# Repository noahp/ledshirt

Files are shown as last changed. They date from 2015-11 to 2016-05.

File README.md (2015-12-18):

# Ledshirt Readme
Battery powered LED flasher.

# Block Diagram
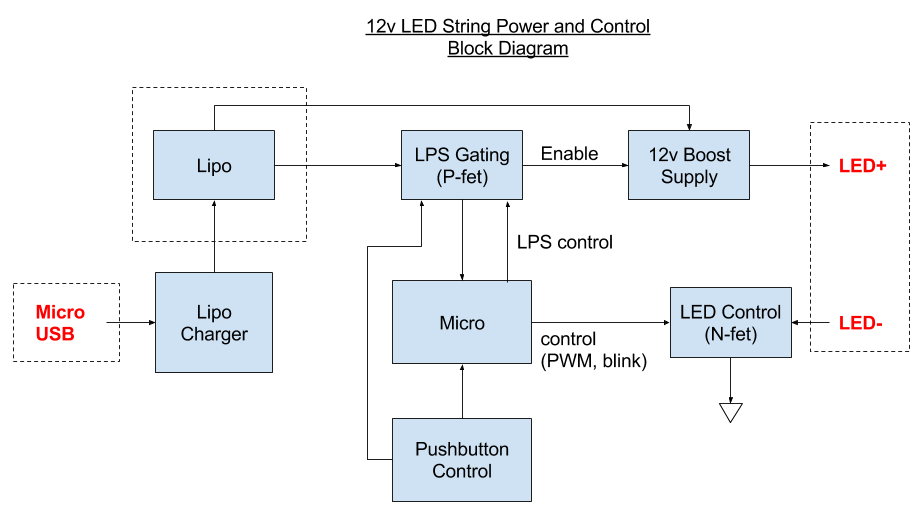
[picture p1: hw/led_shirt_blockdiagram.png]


# 3d Renders
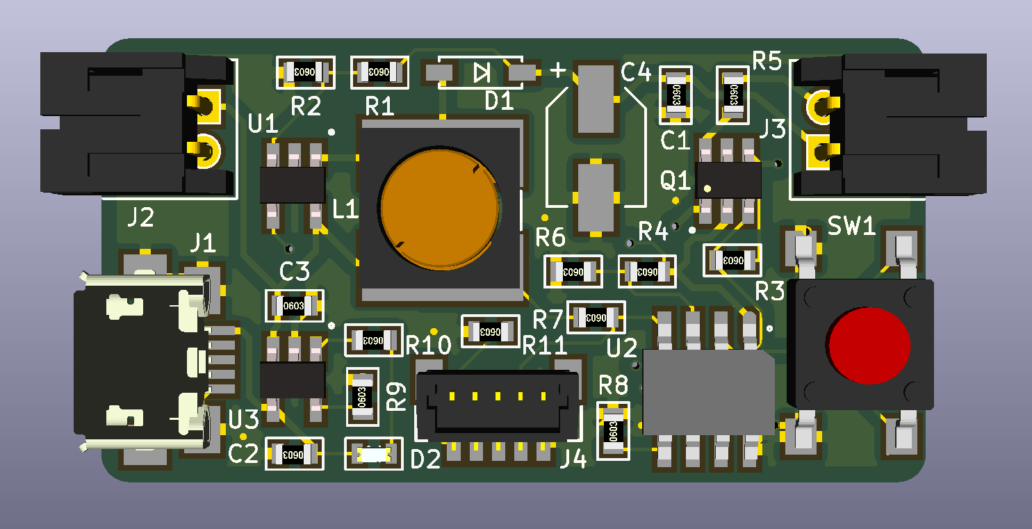
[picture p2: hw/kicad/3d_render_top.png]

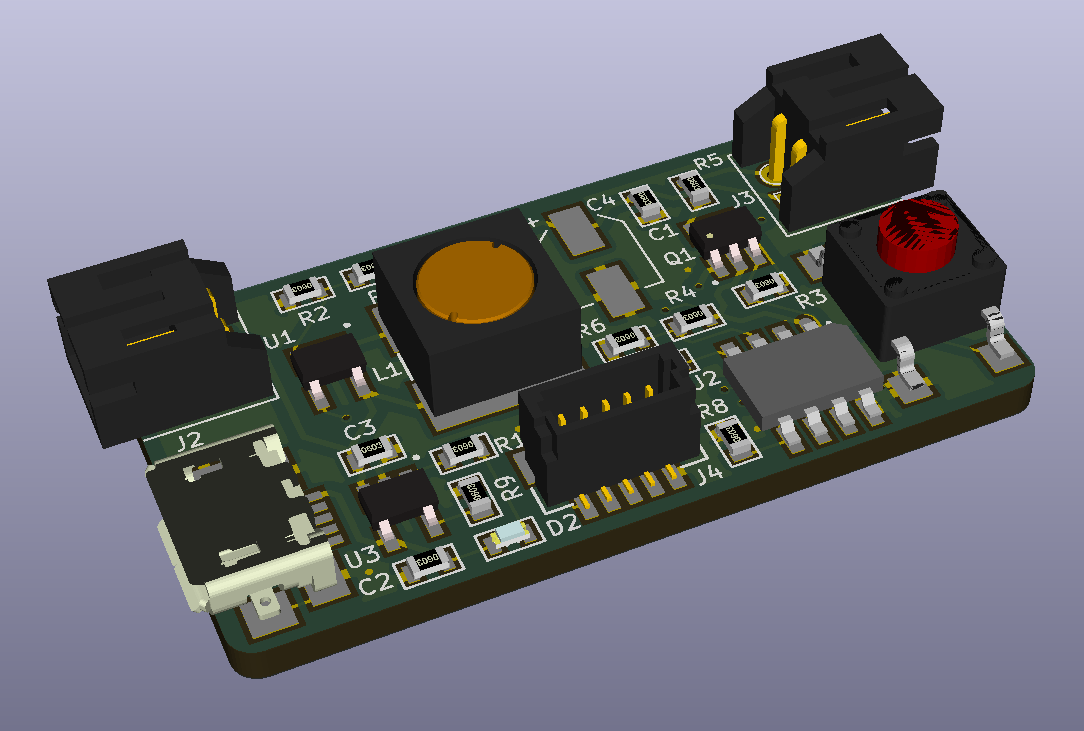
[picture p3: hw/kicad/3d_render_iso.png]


# Parts
|Item|Link|
|----|----|
|Charger|http://ww1.microchip.com/downloads/en/DeviceDoc/21984e.pdf<br/>http://www.microchip.com/wwwproducts/Devices.aspx?dDocName=en024903|
|12v Boost|http://www.digikey.com/product-detail/en/AP3012KTR-G1/AP3012KTR-G1DICT-ND/4505297<br/>http://www.diodes.com/catalog/Boost_Converter_44/AP3012_9395|
|Diode|http://www.mouser.com/Search/ProductDetail.aspx?qs=NQ47qNm99eDyWTEd07miYA%3d%3d|
|Inductor|http://www.digikey.com/product-detail/en/SRR6038-100Y/SRR6038-100YCT-ND/2127571|
|Micro|pic12f1822 [Microchip product page](http://www.microchip.com/wwwproducts/Devices.aspx?dDocName=en544839)<br/>http://www.digikey.com/product-search/en?keywords=PIC12F1822-I%2FSN|
|LEDs|Original cree bare emitters-<br/>http://www.digikey.com/product-detail/en/CLM1B-GKW-CVAXA7A3/CLM1B-GKW-CVAXA7A3CT-ND/3659979<br/>New flexible waterproof strip-<br/>http://www.ebay.com/itm/321843596089?_trksid=p2060353.m2749.l2649&ssPageName=STRK%3AMEBIDX%3AIT|
|FET|P-N SOT23-6<br/>http://www.digikey.com/product-detail/en/DMC2038LVT-7/DMC2038LVT-7DICT-ND/2756074|
|Pushbutton|http://www.digikey.com/product-detail/en/PTS645SK50SMTR92%20LFS/CKN9087CT-ND/1146813|
|USB Micro B|http://www.mouser.com/ProductDetail/FCI/10118192-0001LF|
|Enclosure|Possible options-<br/>http://www.mouser.com/ProductDetail/Bud-Industries/HH-3490<br/>http://www.mouser.com/ProductDetail/New-Age-Enclosures/S3A-202010|

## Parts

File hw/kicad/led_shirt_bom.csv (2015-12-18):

Value | Ref | Footprint
10k | R3 | kicadlib:SMD_0603_R
0 | R5 | kicadlib:SMD_0603_R
4.7F | C3 | kicadlib:SMD_0603_R
3.3k | R9 | kicadlib:SMD_0603_R
3.3k | R10 | kicadlib:SMD_0603_R
LED | D2 | kicadlib:SMD_0603_LED
4.7F | C2 | kicadlib:SMD_0603_R
10103593-0001LF | J1 | kicadlib:usb_micro_b_smt
MCP73831 | U3 | kicadlib:SMD_SOT23-5
PIC12F1822 | U2 | kicadlib:SMD_SOIC-8
10K | R7 | kicadlib:SMD_0603_R
10K | R8 | kicadlib:SMD_0603_R
SW_PUSH | SW1 | kicadlib:spst_pushbutton_smd
PN_MOSFET_DUAL | Q1 | kicadlib:SMD_SOT23-6
AP3012 | U1 | kicadlib:SMD_SOT23-5
5_PIN_HDR | J4 | kicadlib:SMD_JST_5_PIN_VERT
10k | R4 | kicadlib:SMD_0603_R
10k | R6 | kicadlib:SMD_0603_R
D_Schottky | D1 | kicadlib:SMD_SOD-123_DIODE
INDUCTOR | L1 | kicadlib:SMD_IND_6.8x6.8_SRR6038-100Y
2_PIN_HDR | J2 | kicadlib:TH_JST_2PIN_RIGHTANGLE
82k | R1 | kicadlib:SMD_0603_R
10k | R2 | kicadlib:SMD_0603_R
1.0F | C1 | kicadlib:SMD_0603_R
2_PIN_HDR | J3 | kicadlib:TH_JST_2PIN_RIGHTANGLE
CP1 | C4 | kicadlib:SMD_5X5.2_CAP
10K | R11 | kicadlib:SMD_0603_R

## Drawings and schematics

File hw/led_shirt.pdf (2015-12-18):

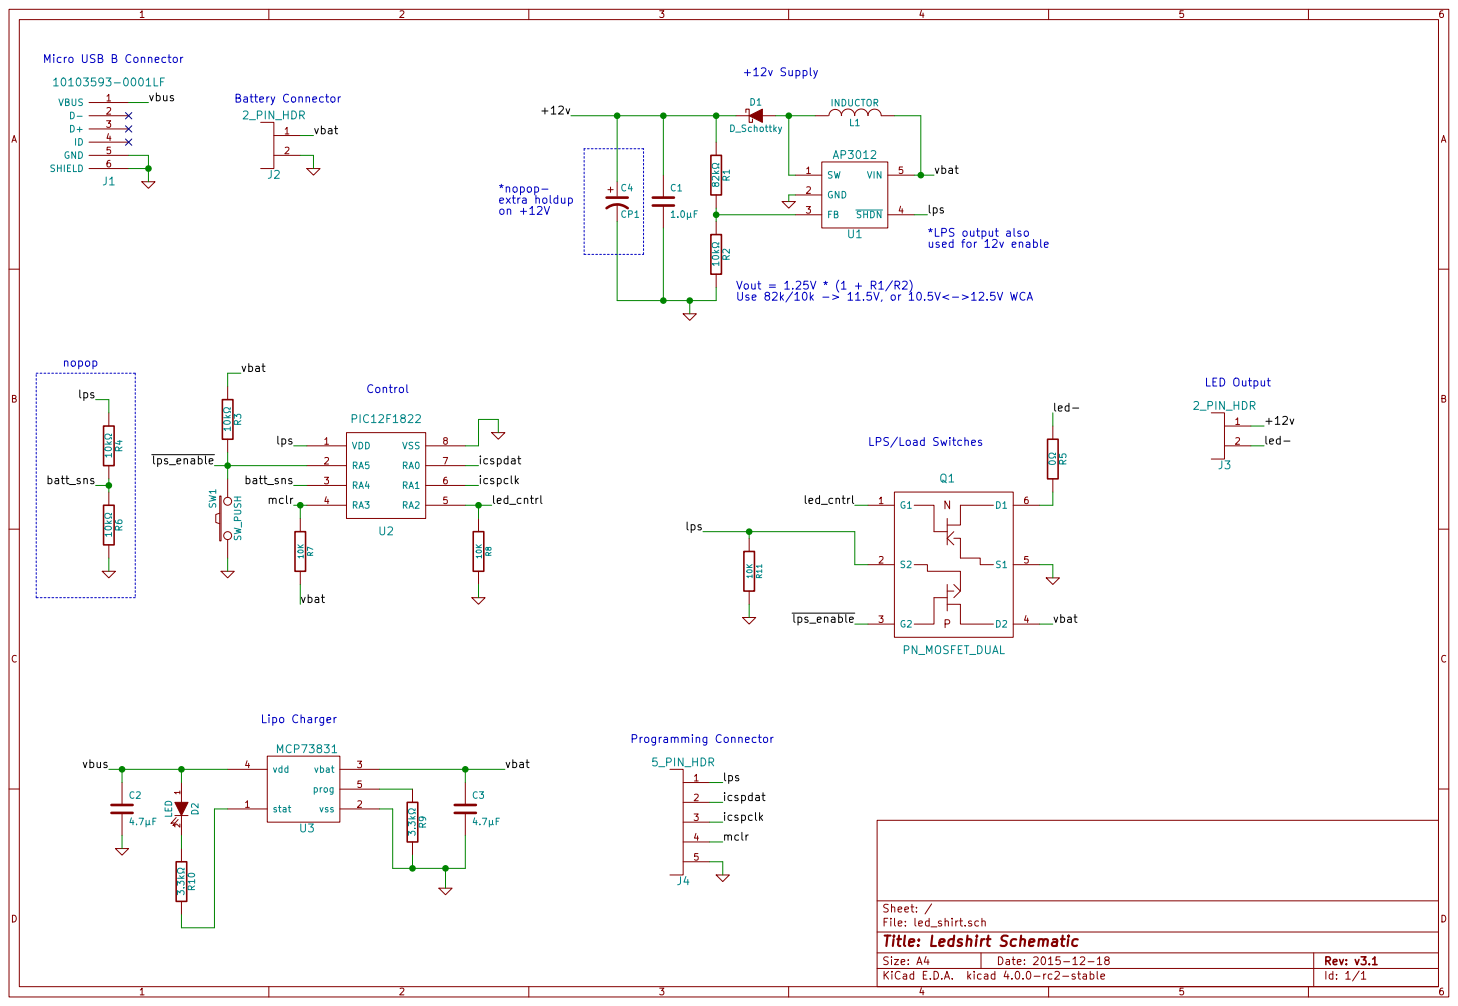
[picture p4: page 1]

INDUCTOR Micro USB B Connector

used for 12v enable +12v Supply
Programming Connector 82k R1 10k R2 C1
LPS/Load Switches C4CP1

File: led_shirt.sch Sheet: /
Id: 1/1 Title: Ledshirt Schematic

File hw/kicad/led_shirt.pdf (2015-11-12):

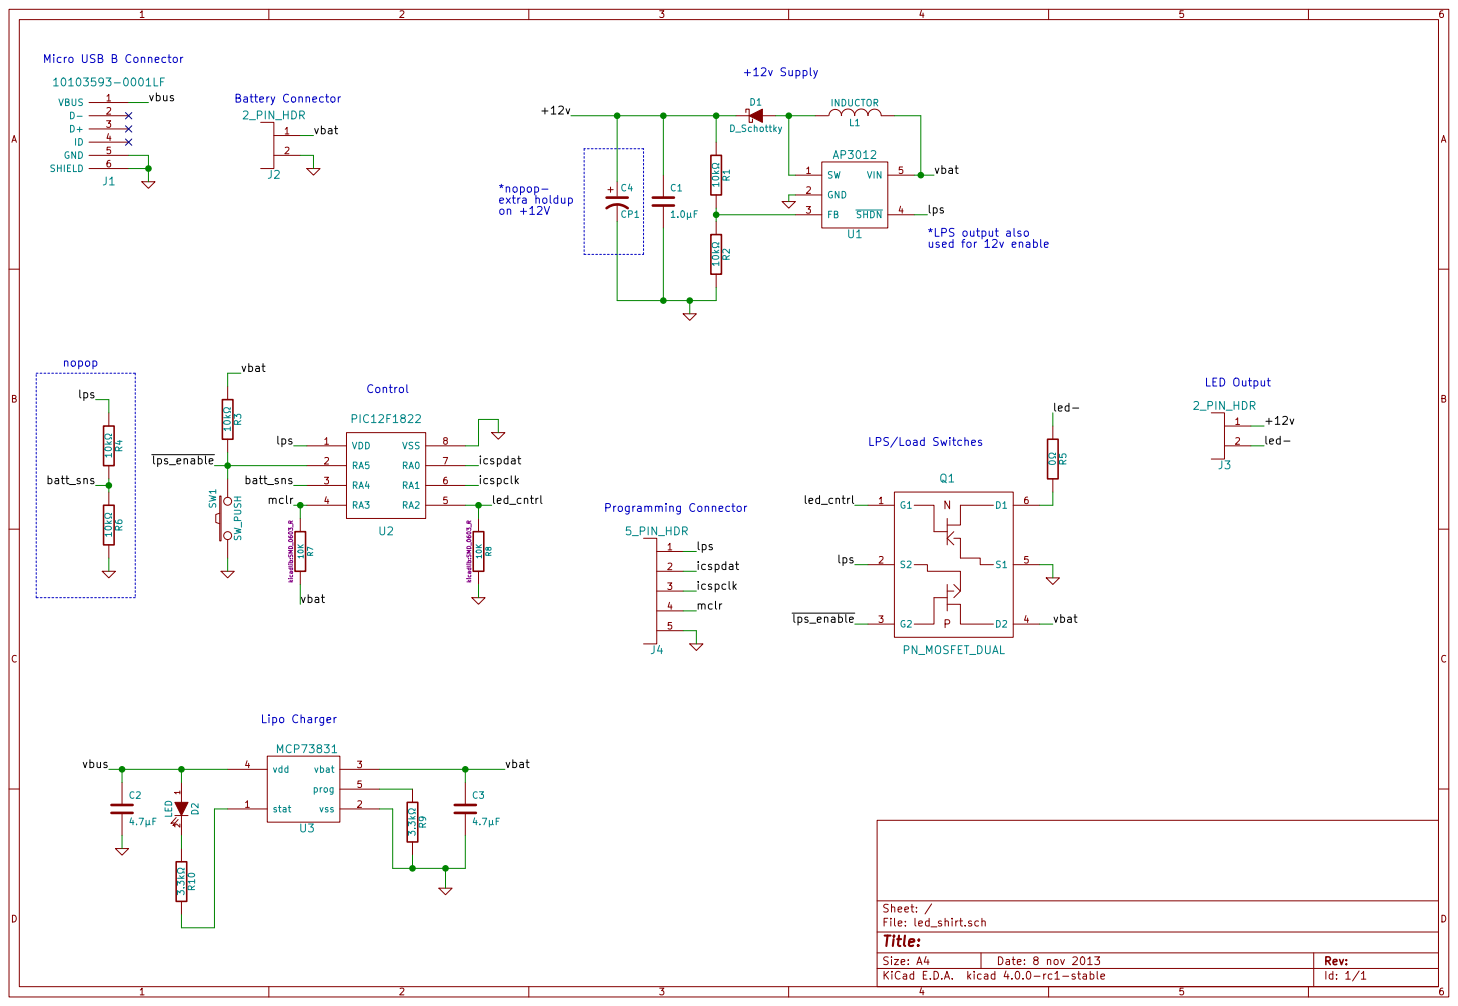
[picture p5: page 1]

INDUCTOR Micro USB B Connector

used for 12v enable +12v Supply
Programming Connector10k R1 10k R2 C1
LPS/Load Switches C4CP1

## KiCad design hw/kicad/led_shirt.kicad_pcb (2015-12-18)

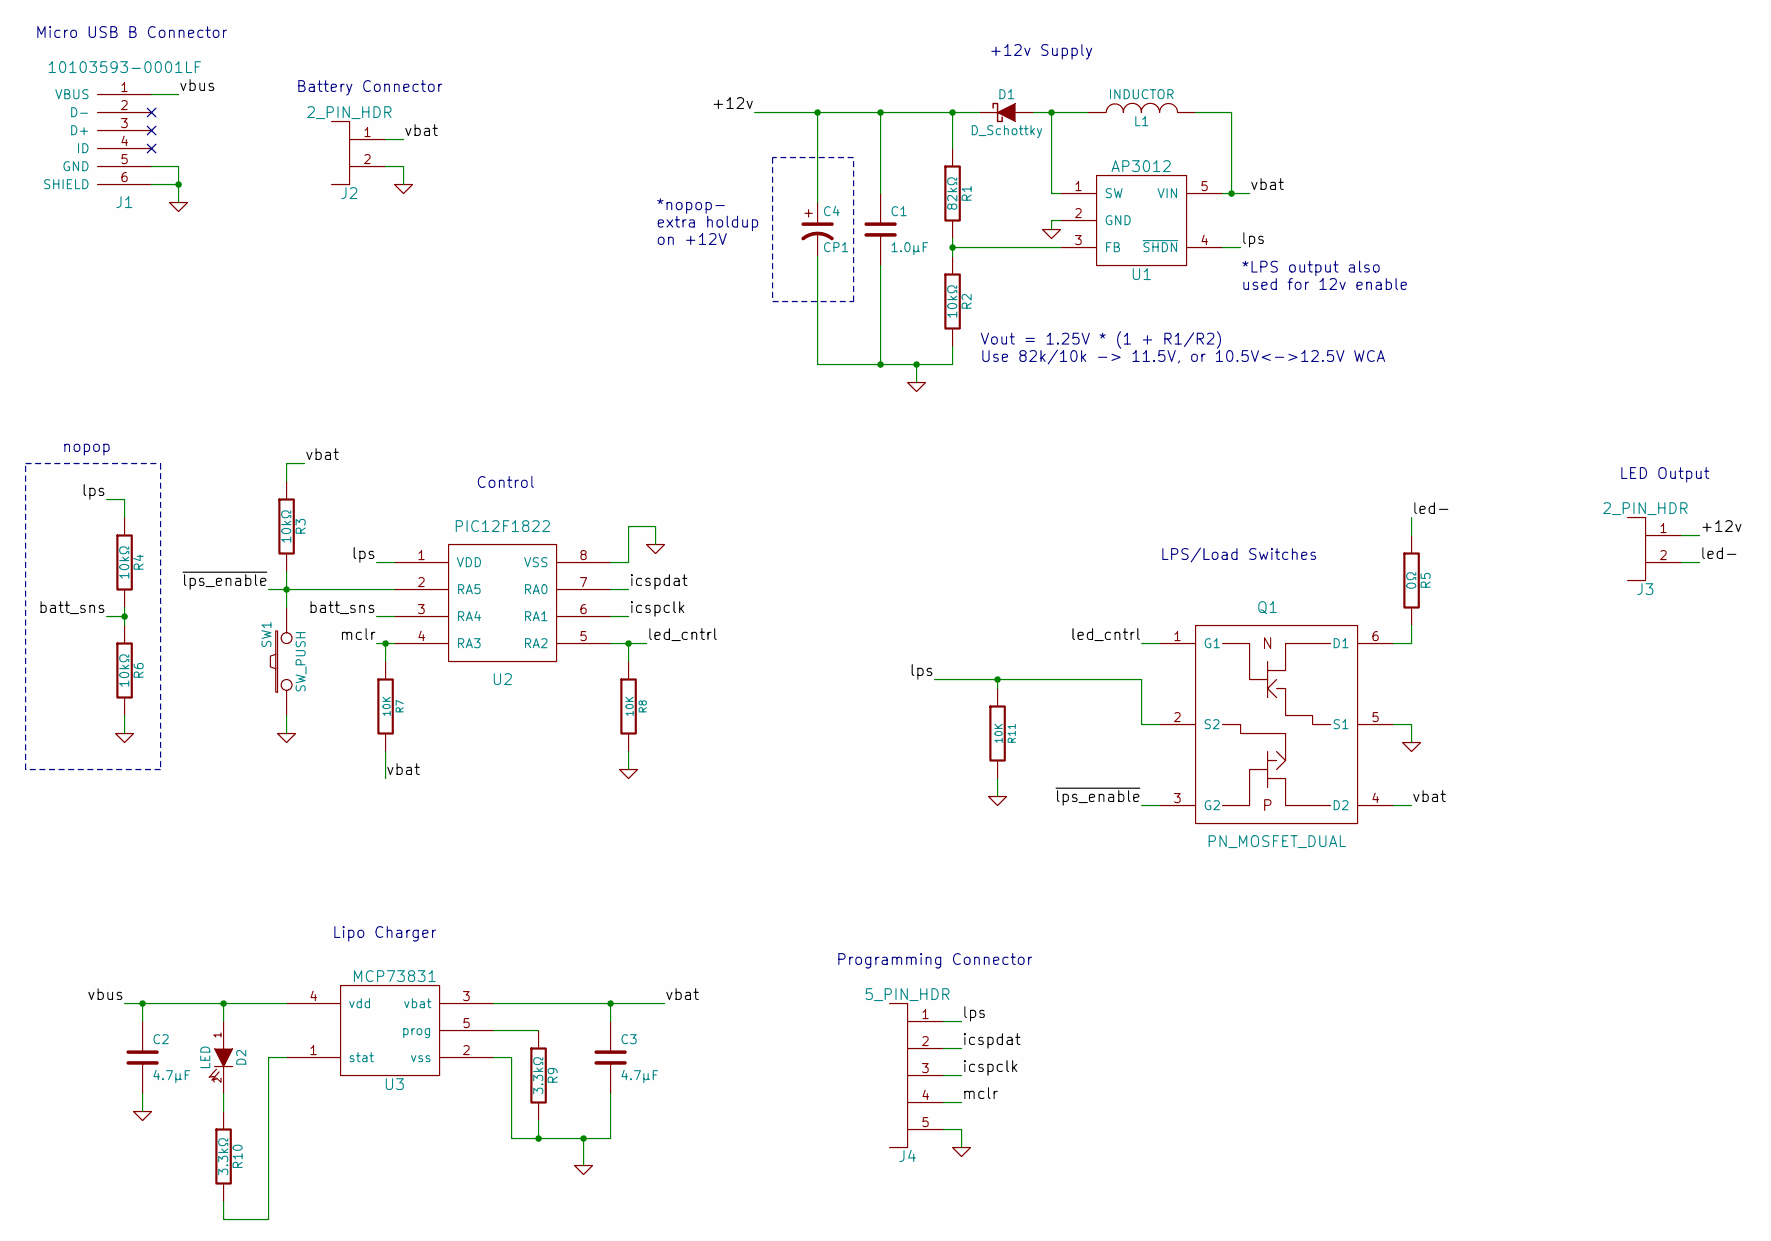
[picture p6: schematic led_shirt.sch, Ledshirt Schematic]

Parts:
C1: 1.0µF; SMD_0603_R
C2, C3: 4.7µF; SMD_0603_R
C4: CP1; SMD_5X5.2_CAP
D1: D_Schottky; SMD_SOD-123_DIODE
D2: LED; SMD_0603_LED
J1: 10103593-0001LF; usb_micro_b_smt
J2, J3: 2_PIN_HDR; TH_JST_2PIN_RIGHTANGLE
J4: 5_PIN_HDR; SMD_JST_5_PIN_VERT
L1: INDUCTOR; SMD_IND_6.8x6.8_SRR6038-100Y
Q1: PN_MOSFET_DUAL; SMD_SOT23-6
R1: 82kΩ; SMD_0603_R
R2, R3, R4, R6: 10kΩ; SMD_0603_R
R5: 0Ω; SMD_0603_R
R7, R8, R11: 10K; SMD_0603_R
R9, R10: 3.3kΩ; SMD_0603_R
SW1: SW_PUSH; spst_pushbutton_smd
U1: AP3012; SMD_SOT23-5
U2: PIC12F1822; SMD_SOIC-8
U3: MCP73831; SMD_SOT23-5

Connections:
/+12v: C1.1, C4.1, D1.1 (K), J3.1, R1.1
/batt_sns: R4.2, R6.1, U2.3 (RA4)
/icspclk: J4.3, U2.6 (RA1)
/icspdat: J4.2, U2.7 (RA0)
/led-: J3.2, R5.1
/led_cntrl: Q1.1 (G1), R8.1, U2.5 (RA2)
/lps: J4.1, Q1.2 (S2), R4.1, R11.1, U1.4 (~SHDN), U2.1 (VDD)
/mclr: J4.4, R7.1, U2.4 (RA3)
/vbat: C3.1, J2.1, L1.2, Q1.4 (D2), R3.1, R7.2, U1.5 (VIN), U3.3 (vbat)
/vbus: C2.1, D2.1 (A), J1.1 (VBUS), U3.4 (vdd)
/~lps_enable: Q1.3 (G2), R3.2, SW1.2, U2.2 (RA5)
GND: C1.2, C2.2, C3.2, C4.2, J1.5 (GND), J1.6 (SHIELD), J2.2, J4.5, Q1.5 (S1), R2.2, R6.2, R8.2, R9.2, R11.2, SW1.1, U1.2 (GND), U2.8 (VSS), U3.2 (vss)
unnamed: D1.2 (A), L1.1, U1.1 (SW)
unnamed: D2.2 (K), R10.1
unnamed: Q1.6 (D1), R5.2
unnamed: R1.2, R2.1, U1.3 (FB)
unnamed: R9.1, U3.5 (prog)
unnamed: R10.2, U3.1 (stat)

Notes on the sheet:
Lipo Charger
Control
nopop
Micro USB B Connector
Battery Connector
Programming Connector
*LPS output also used for 12v enable
+12v Supply
LED Output
LPS/Load Switches
*nopop- extra holdup on +12V
Vout = 1.25V * (1 + R1/R2) Use 82k/10k -> 11.5V, or 10.5V<->12.5V WCA

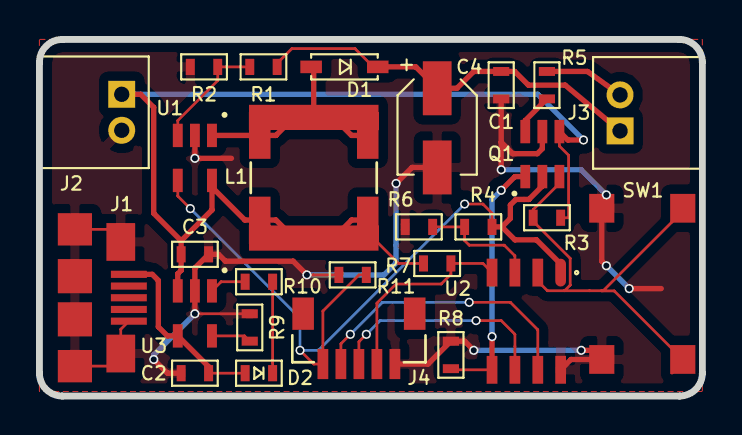
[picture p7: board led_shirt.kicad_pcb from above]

Board: 2 copper layers, 36.8 x 19.8 mm, 27 parts (0 on the bottom side), 18 nets.

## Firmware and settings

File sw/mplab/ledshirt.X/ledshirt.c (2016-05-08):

/*
 ledshirt.c
 * main file for blinky led shirt.
 * https://github.com/noahp/ledshirt.git
 */

// PIC12F1822 Configuration Bit Settings

#include <xc.h>

// #pragma config statements should precede project file includes.
// Use project enums instead of #define for ON and OFF.

// CONFIG1
#pragma config FOSC = INTOSC    // Oscillator Selection (INTOSC oscillator: I/O function on CLKIN pin)
#pragma config WDTE = OFF       // Watchdog Timer Enable (WDT disabled)
#pragma config PWRTE = OFF      // Power-up Timer Enable (PWRT disabled)
#pragma config MCLRE = ON       // MCLR Pin Function Select (MCLR/VPP pin function is MCLR)
#pragma config CP = OFF         // Flash Program Memory Code Protection (Program memory code protection is disabled)
#pragma config CPD = OFF        // Data Memory Code Protection (Data memory code protection is disabled)
#pragma config BOREN = ON       // Brown-out Reset Enable (Brown-out Reset enabled)
#pragma config CLKOUTEN = OFF   // Clock Out Enable (CLKOUT function is disabled. I/O or oscillator function on the CLKOUT pin)
#pragma config IESO = ON        // Internal/External Switchover (Internal/External Switchover mode is enabled)
#pragma config FCMEN = ON       // Fail-Safe Clock Monitor Enable (Fail-Safe Clock Monitor is enabled)

// CONFIG2
#pragma config WRT = OFF        // Flash Memory Self-Write Protection (Write protection off)
#pragma config PLLEN = ON       // PLL Enable (4x PLL enabled)
#pragma config STVREN = ON      // Stack Overflow/Underflow Reset Enable (Stack Overflow or Underflow will cause a Reset)
#pragma config BORV = LO        // Brown-out Reset Voltage Selection (Brown-out Reset Voltage (Vbor), low trip point selected.)
#pragma config LVP = ON         // Low-Voltage Programming Enable (Low-voltage programming enabled)

#include <stdlib.h>
#include <stdint.h>

//config main clock
void config_clock(void)
{
    // set high speed internal oscillator @ 16MHz
    OSCCONbits.IRCF = 0b1111;

    // wait for osc. to be ready to use
    while(!OSCSTATbits.HFIOFR);
}

//config port pins
void config_port(void)
{
    // porta
    PORTA = 0;
    LATA = 0;
    ANSELA = 0;
    TRISA = 0b11111011;     // A5 input, A2 output

    // pwm P1A on pin A2
    //APFCONbits.CCP1SEL = 0;
}

//config timer
void config_timer(void)
{
    // setup timer0
    TMR0 = 0;
    OPTION_REGbits.TMR0CS = 0;
    OPTION_REGbits.PSA = 1;
    //OPTION_REGbits.PS = 0b111;  // 1:256 scale
    // we want to overflow after 250 instruction cycles to make math nicer
    TMR0bits.TMR0 = 5;
}

//config pwm
void config_pwm(void)
{
    // tmr2 config
    T2CONbits.T2CKPS = 0b00;    //prescale is 1
    PR2bits.PR2 = 19;           //19+1 for 50kHz operation
    T2CONbits.TMR2ON = 1;       //tmr2 on

    // pwm1A on A2
    CCP1CONbits.CCP1M = 0b1100; //PWM mode: P1A, P1C active-high
    CCP1CONbits.P1M = 0b00;     //00 = Single output; P1A modulated
    CCPR1Lbits.CCPR1L = 0b00000111; //pwm duty cycle msb's
    CCP1CONbits.DC1B = 0b11;    //pwm duty cycle lsb's
}

//config interrupts
void config_interrupts(void)
{
    // clear and get ready for tmr0 interrupt
    INTCONbits.TMR0IF = 0;
    INTCONbits.GIE = 1;
    INTCONbits.PEIE = 1;
    
    
    INTCONbits.TMR0IE = 1;      //tmr0 interrupt on
}

void sleepy(void)
{
    INTCONbits.TMR0IF = 0;
    INTCONbits.TMR0IE = 0;
    TRISAbits.TRISA2 = 1;       //pwm output disable
    T2CONbits.TMR2ON = 0;       //tmr2 off
    LATAbits.LATA5 = 0;
}

void wakey(void)
{
    INTCONbits.TMR0IE = 1;      //tmr0 interrupt on
    T2CONbits.TMR2ON = 1;       //tmr2 on
}

void enable_ext_interrupts(void)
{
    IOCAFbits.IOCAF5 = 0;
    IOCANbits.IOCAN5 = 1;
    INTCONbits.IOCIF = 0;
    INTCONbits.IOCIE = 1;
}

void disable_ext_interrupts(void)
{
    INTCONbits.IOCIE = 1;
    INTCONbits.IOCIF = 0;
    IOCANbits.IOCAN5 = 1;
    IOCAFbits.IOCAF5 = 0;
}

#define NUM_MODES 3
unsigned int blinkMode = 1; // on reset, blink is active
unsigned int wakeUp = 0;
char LED_ON = 1;

void interrupt ISR(void)
{
    static unsigned char blinkStage = 0;
    static unsigned int counter = 0;
    static unsigned int buttonPress = 0;
#define BUTTONDEBOUNCE 320

    if(IOCAFbits.IOCAF5){
        IOCAFbits.IOCAF5 = 0;
        disable_ext_interrupts();
        wakeUp = 500;
        wakey();
    }
    
    if(INTCONbits.TMR0IF){
        INTCONbits.TMR0IF = 0;

        // we want to overflow after 250 instruction cycles to make math nicer
        TMR0bits.TMR0 = 5;

        // control pwm here
        if(LED_ON){
            //LATAbits.LATA2 = 1;
            //TRISAbits.TRISA2 = 0;       // pwm output enable
            // set output high
            PORTAbits.RA2 = 1;
            LATAbits.LATA2 = 1;
        }
        else{
            //LATAbits.LATA2 = 0;
            //TRISAbits.TRISA2 = 1;       // pwm output disable
            // set output low too
            PORTAbits.RA2 = 0;
            LATAbits.LATA2 = 0;
        }

        // run mode managed here (every 10ms)
        if(counter++ > 160){
            counter = 0;

            // wakeUp timeout
            if(wakeUp){
                wakeUp--;
            }

            // run button check here
            if(0){//!PORTAbits.RA5){
                if(buttonPress++ > 30){
                    buttonPress = 0;
                    blinkMode = (blinkMode + 1)%NUM_MODES;
                }
            }
            else{
                buttonPress = 0;
            }

            switch(blinkMode){
                default:
                    blinkMode = 0;
                case 0:
                    LED_ON = 0;
                    break;
                case 1:
                    if(blinkStage < 3){
                        LED_ON = 1;
                    }
                    else{
                        LED_ON = 0;
                    }

                    blinkStage = (blinkStage+1)%15;
                    break;
                case 2:
                    LED_ON = 1;
                    break;
            }
        }
    }
}

void main(int argc, char** argv) {
    // init
    config_clock();
    config_port();
    
    // below is probably redundant
    PORTAbits.RA2 = 1;
    LATAbits.LATA2 = 1;
            
    config_timer();
    config_interrupts();
    //config_pwm();

    while(1){
        // sleep when led is off, until ext interrupt wakes us up
        if((blinkMode == 0) && (wakeUp == 0)){
            // enable external interrupt on A5
            enable_ext_interrupts();
            sleepy();
            asm("SLEEP");
        }
    }
}

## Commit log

2012-12-11 - add all from bitbucket
    [led_shirt.brd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]
2012-12-11 - add pictures of the pcb
2012-12-11 - fix pcb pic url ref
2012-12-11 - comment about pic footprint issue
2012-12-12 - change footprint for pic to tssop-14 (was soic-14)
    [led_shirt.brd]
2012-12-12 - add pic of charging
2012-12-18 - timer interrupt working
2012-12-19 - use tmr1 int for "pwm", tmr0 for on/off & button debounce (may move button debounce to tmr2? or speed up timr0)
2012-12-21 - use pwm hw instead of tmr1 for driving the leds.
2012-12-24 - add pwm4
2013-10-18 switch to pic12f1822
    [led_shirt.sch]
2013-10-18 add new pcb
    [led_shirt.kicad_pcb]
2013-10-18 remove old board file
    [led_shirt.brd]
2013-10-18 rev 2 board done
    [led_shirt-B_Cu.gbl, led_shirt-B_Mask.gbs, led_shirt-B_SilkS.gbo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]
2013-10-22 update gerbys.
    [led_shirt-B_Cu.gbl, led_shirt-B_Mask.gbs, led_shirt-B_SilkS.gbo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]
2013-10-23 - add 10k pullup to mclr and 10k pulldown to fet gate (startup sequencing)
    [led_shirt.sch]
2013-10-23 - update pcb & gerbers with new pullups
    [led_shirt-B_Mask.gbs, led_shirt-B_SilkS.gbo, led_shirt-Back.gbl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]
2013-10-23 - update sch & pcb screengrabs. add pdf of schematic.
2013-11-05 - cleanup - add led's to schematic instead of test point breakout
    [led_shirt.sch]
2013-11-05 - add kicadlib
2013-11-06 - add plcc2 footprint & make cmplist
2013-11-06 - start layout
    [led_shirt.kicad_pcb]
2013-11-07 - two sides! also delete programming pins, who needs 'em
    [led_shirt.kicad_pcb, led_shirt.sch]
2013-11-08 work on pcb
    [led_shirt.kicad_pcb, led_shirt.sch]
2013-11-08 new pcb
    [led_shirt-B_Cu.gbl, led_shirt-B_Mask.gbs, led_shirt-B_SilkS.gbo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]
2013-11-08 - ordered
    [led_shirt-B_Mask.gbs, led_shirt-B_SilkS.gbo, led_shirt-Back.gbl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]
2013-11-08 - missed something
    [led_shirt.kicad_pcb]
2013-11-23 - switch config from PIC16F1503 to PIC12F1822
2013-11-23 - add pwm, works
2013-11-25 - reduce pwm freq. to 50kHz from 100kHz to drop power loss in fet
2013-11-25 - move charge led to front >_<
    [led_shirt-B_Mask.gbs, led_shirt-B_SilkS.gbo, led_shirt-Back.gbl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]
2015-10-30 save some changes. need to switch to dual n-fet package.
    [led_shirt.kicad_pcb, led_shirt.sch]
2015-10-30 add dual fet symbol
2015-10-30 fix up fet symbol and connect it
    [led_shirt.sch]
2015-11-03 update sch
    [led_shirt.kicad_pcb, led_shirt.sch]
2015-11-10 fix labels
    [led_shirt.sch]
2015-11-10 finish sch, add bom
    [led_shirt.sch, led_shirt_bom.csv]
2015-11-11 more components
    [led_shirt.kicad_pcb, led_shirt.sch]
2015-11-12 footprints mostly done, some missing modules
    [led_shirt.csv, led_shirt.kicad_pcb, led_shirt.sch]
2015-11-12 add usb micro b model
    [led_shirt.kicad_pcb]
2015-11-20 parts positioned, silks. next is traces.
    [led_shirt.kicad_pcb, led_shirt.sch]
2015-11-20 layout done
    [led_shirt.kicad_pcb]
2015-11-20 add screw mounts, which adds $1.60 to osh price. also need to reposition usb connector if I use screw mounts.
    [led_shirt.kicad_pcb, led_shirt_bom.csv]
2015-11-20 update 12v boost feedback resistor divider
    [led_shirt.sch]
2015-11-22 save gerbers and new renders
    [led_shirt-B_Cu.gbl, led_shirt-B_Mask.gbs, led_shirt-B_SilkS.gbo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]
2015-11-22 update gerbers zip
2015-11-22 refresh gerbers.
    [led_shirt-B_Cu.gbl, led_shirt-B_Mask.gbs, led_shirt-B_SilkS.gbo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]
2015-12-18 add button to block diagram
2015-12-18 add add pull-down to lps net, to prevent p-fet leakage from enabling 12v boost when lps is disabled
    [led_shirt.kicad_pcb, led_shirt.sch, led_shirt_bom.csv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]
2016-05-08 led on by default, adjust blink mode to lower duty cycle, disable button
2016-05-14 new kicadlib
